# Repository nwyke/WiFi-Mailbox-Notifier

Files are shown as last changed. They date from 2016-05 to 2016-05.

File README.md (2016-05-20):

# WiFi Mailbox Notifier

This board notifies you when you get mail. JST-PH connector for 3.7V lithium ion battery (min 500mA), USB connector for power and battery charging, auto-reset for ESP-module, battery voltage measurement. 

Inspired by [hal9k "postkasse overvaagning"](https://hal9k.dk/postkasse-overvaagning/). Boards can be found on [OSHPark](https://oshpark.com/shared_projects/7UJ1nXM0) (not tested yet!).

Please support us and open-source hardware by purchasing products from
[MiniElektro.dk](http://minielektro.dk)/[MiniElektro.se](http://minielektro.se).

Content
-------------------
* **/Hardware**
  * All Eagle design files (.brd, .sch)
  * PDF schematic
  * BOM

License
-------------------
The hardware is released under [Creative Commons ShareAlike 4.0 International](https://creativecommons.org/licenses/by-sa/4.0/).

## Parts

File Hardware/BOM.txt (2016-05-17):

Part Value        Device                Package                      Description          BTM_NEG BTM_POS PROD_ID    TOP_NEG TOP_POS VALUE 
C2   100nF        CAP1206               1206                         Capacitor                                                             
C4   10uF         CAP1206               1206                         Capacitor                                                             
C5   10uF         CAP1206               1206                         Capacitor                                                             
D1   16V          DIODE-ZENER16V        SOD-123                      Zener Diode                          DIO-12440                  16V   
D2   16V          DIODE-ZENER16V        SOD-123                      Zener Diode                          DIO-12440                  16V   
D3   16V          DIODE-ZENER16V        SOD-123                      Zener Diode                          DIO-12440                  16V   
D5   16V          DIODE-ZENER16V        SOD-123                      Zener Diode                          DIO-12440                  16V   
D6   YELLOW       LED-YELLOW1206        LED-1206                     Yellow SMD LEDs                      DIO-00820                  YELLOW
J1                M06SILK_FEMALE_PTH    1X06                         Header 6                             CONN-08437                       
J2                M02LOCK               1X02_LOCK                    Standard 2-pin 0.1"                                                   
J4                JST_2MM_MALE          JST-2-SMD                    Mates to single-cell -       +       CONN-11443 -       +             
R1   1K           RESISTOR1206          1206                         Resistor                                                              
R2   2K           RESISTOR1206          1206                         Resistor                                                              
R3   10K          RESISTOR1206          1206                         Resistor                                                              
R7   1M           RESISTOR1206          1206                         Resistor                                                              
R8   220          RESISTOR1206          1206                         Resistor                                                              
R9   10K          RESISTOR1206          1206                         Resistor                                                              
R10  10K          RESISTOR1206          1206                         Resistor                                                              
R11  10K          RESISTOR1206          1206                         Resistor                                                              
R12  10K          RESISTOR1206          1206                         Resistor                                                              
R13  10K          RESISTOR1206          1206                         Resistor                                                              
SW1               SWITCH_SPST_4_PINRECT TACTILE_SWITCH_SMD_4.6X2.8MM                                      SWCH-13065                       
U$3  USB-MICROB"  USB-MICROB"           USB-B-MICRO-SMD_V03                                               CONN-11752                       
U1                ESP12ESMD             ESP12E-SMD                   ESP12E Module                                                         
U3   V_REG_LDOSMD V_REG_LDOSMD          SOT23-5                      Voltage Regulator LD                                                  
U5   MCP73831     MCP73831              SOT23-5

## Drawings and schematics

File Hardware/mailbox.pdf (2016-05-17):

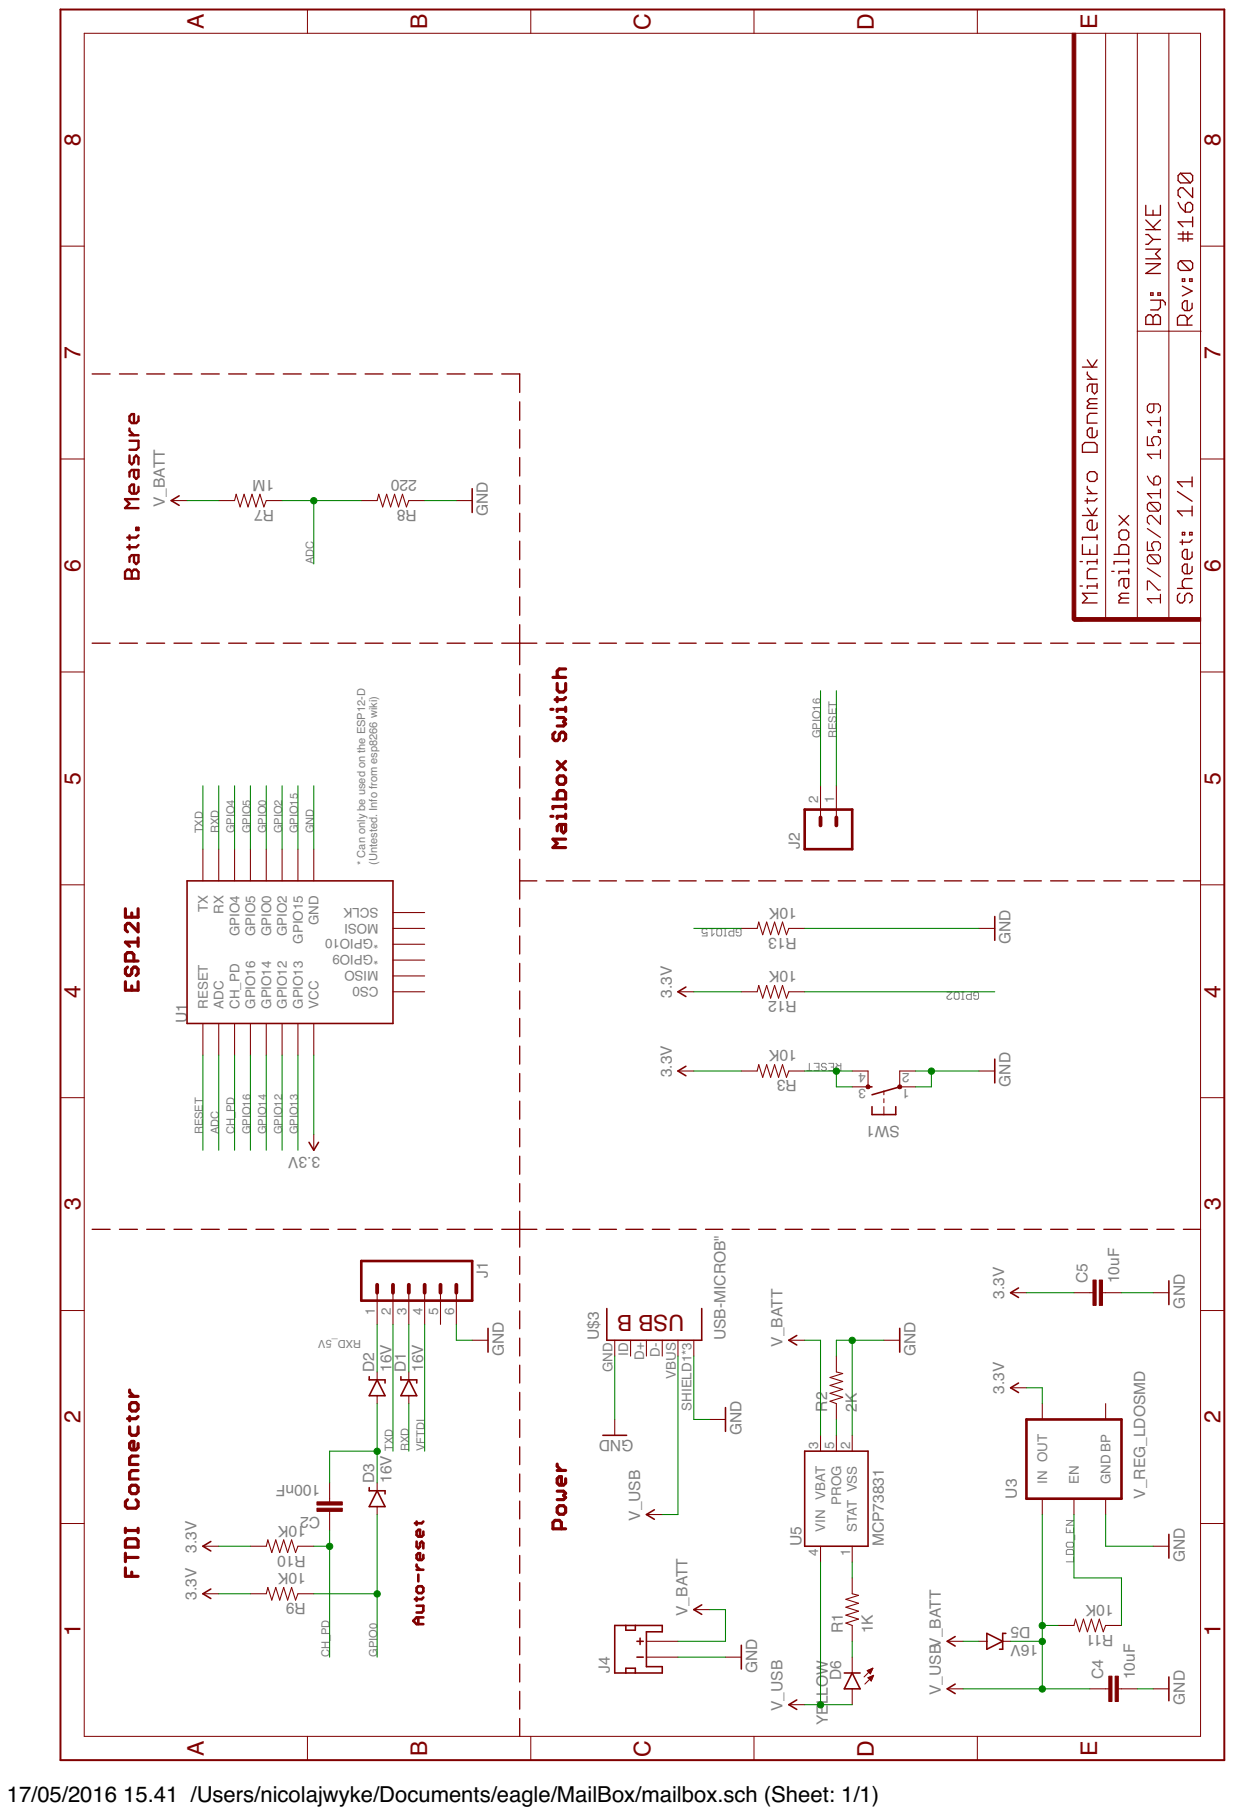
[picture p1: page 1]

* Can only be used on the ESP12-D

(Untested. Info from esp8266 wiki) GND

3.3V USB-MICROB" GND GND

17/05/2016 15.41 /Users/nicolajwyke/Documents/eagle/MailBox/mailbox.sch (Sheet: 1/1)

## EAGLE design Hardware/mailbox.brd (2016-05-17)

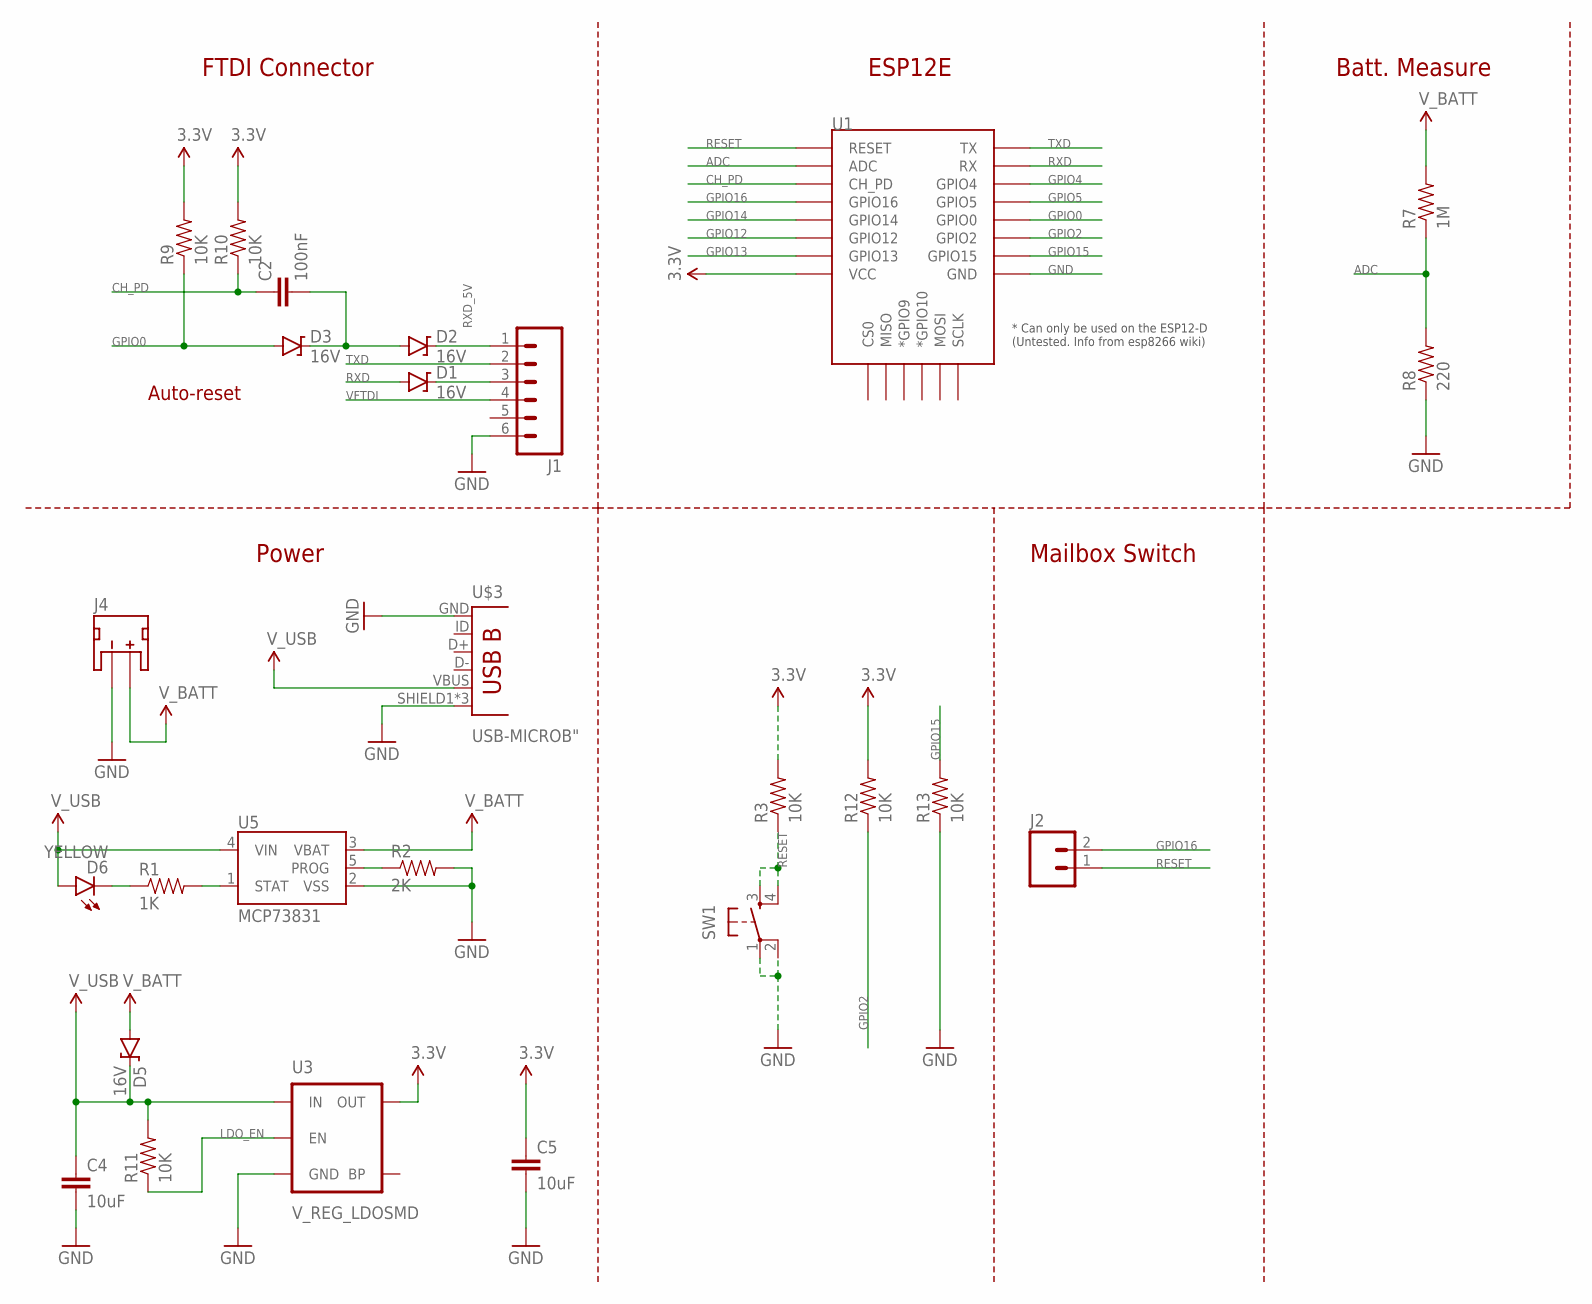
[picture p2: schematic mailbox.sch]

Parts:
C2: 100nF; 1206
C4, C5: 10uF; 1206
D1, D2, D3, D5: 16V; SOD-123
D6: YELLOW; LED-1206
J1: M06SILK_FEMALE_PTH; 1X06
J2: M02LOCK; 1X02_LOCK
J4: JST_2MM_MALE; JST-2-SMD
R1: 1K; 1206
R2: 2K; 1206
R3, R9, R10, R11, R12, R13: 10K; 1206
R7: 1M; 1206
R8: 220; 1206
SW1: SWITCH_SPST_4_PINRECT; TACTILE_SWITCH_SMD_4.6X2.8MM
U1: ESP12ESMD; ESP12E-SMD
U3: V_REG_LDOSMD; SOT23-5
U5: MCP73831; SOT23-5
U$3: USB-MICROB"; USB-B-MICRO-SMD_V03

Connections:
3.3V: C5.1, R3.2, R9.2, R10.2, R12.2, U1.VCC, U3.5 (OUT)
ADC: R7.1, R8.2, U1.ADC
CH_PD: C2.1, R10.1, U1.CH_PD
GND: C4.2, C5.2, J1.6, J4.1 (-), R2.2, R8.1, R13.1, SW1.1, SW1.2, U1.GND, U3.2 (GND), U5.2 (VSS), U$3.GND, U$3.SHIELD1 (SHIELD), U$3.SHIELD2 (SHIELD), U$3.SHIELD3 (SHIELD)
GPIO0: D3.A, R9.1, U1.GPIO0
GPIO2: R12.1, U1.GPIO2
GPIO4: U1.GPIO4
GPIO5: U1.GPIO5
GPIO12: U1.GPIO12
GPIO13: U1.GPIO13
GPIO14: U1.GPIO14
GPIO15: R13.2, U1.GPIO15
GPIO16: J2.2, U1.GPIO16
LDO_EN: R11.1, U3.3 (EN)
unnamed: D6.C, R1.1
unnamed: D2.C, J1.1
unnamed: C2.2, D2.A, D3.C
unnamed: R1.2, U5.1 (STAT)
unnamed: R2.1, U5.5 (PROG)
RESET: J2.1, R3.1, SW1.3, SW1.4, U1.RESET
RXD: D1.A, U1.RXD0 (RX)
RXD_5V: D1.C, J1.3
TXD: J1.2, U1.TXD0 (TX)
VFTDI: J1.4
V_BATT: D5.A, J4.2 (+), R7.2, U5.3 (VBAT)
V_USB: C4.1, D5.C, D6.A, R11.2, U3.1 (IN), U5.4 (VIN), U$3.VBUS

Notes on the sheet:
FTDI Connector
Auto-reset
ESP12E
Power
Mailbox Switch
Batt. Measure

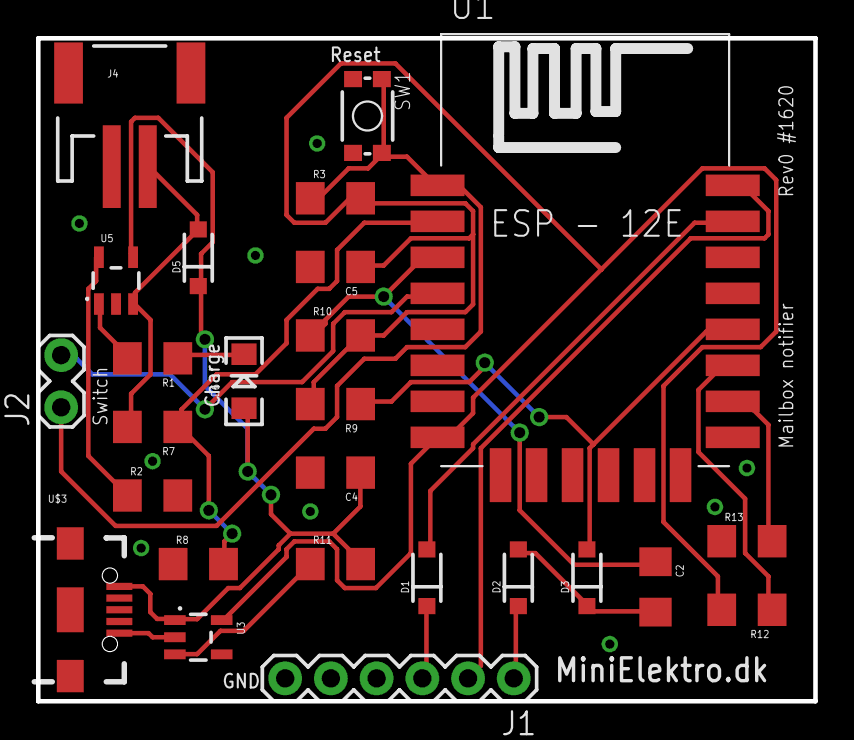
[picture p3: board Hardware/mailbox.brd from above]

Board: 2 copper layers, 43.2 x 36.8 mm, 26 parts (0 on the bottom side), 20 nets.

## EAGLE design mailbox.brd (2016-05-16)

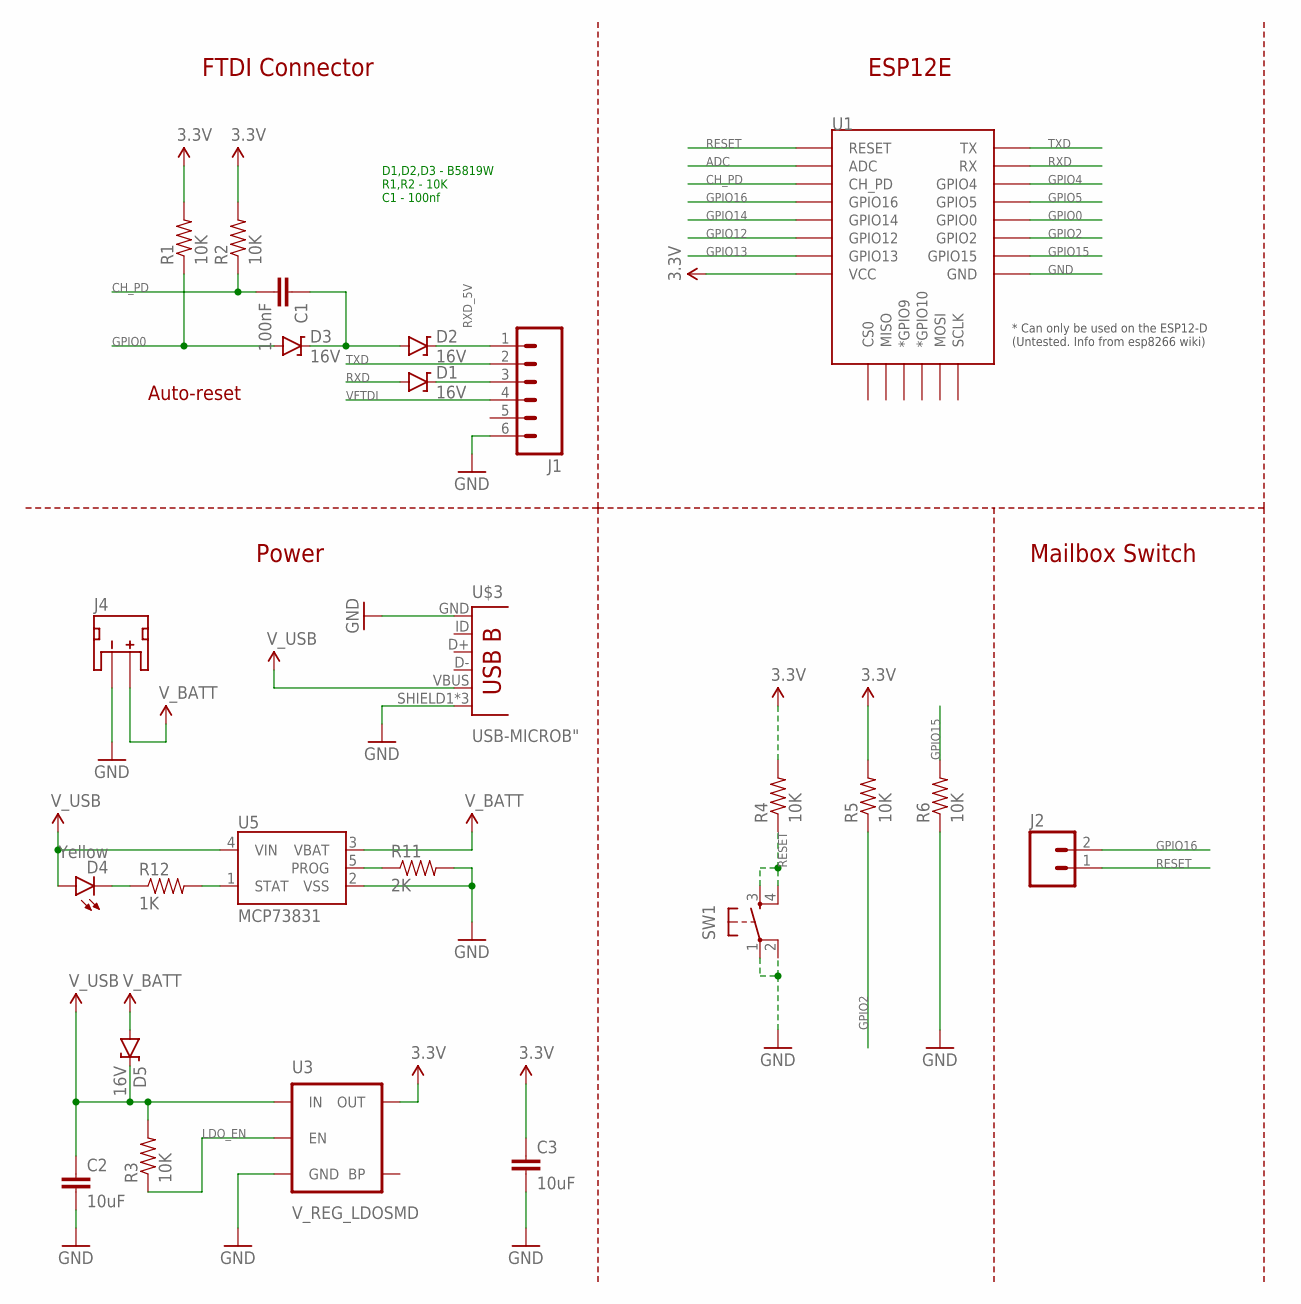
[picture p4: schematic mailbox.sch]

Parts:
C1: 100nF; 0402-CAP
C2, C3: 10uF; 0402-CAP
D1, D2, D3, D5: 16V; SOD-123
D4: Yellow; LED-0603
J1: M06SILK_FEMALE_PTH; 1X06
J2: M02LOCK; 1X02_LOCK
J4: JST_2MM_MALE; JST-2-SMD
R1, R2, R3, R4, R5, R6: 10K; 0402-RES
R11: 2K; 0603-RES
R12: 1K; 0603-RES
SW1: SWITCH_SPST_4_PINRECT; TACTILE_SWITCH_SMD_4.6X2.8MM
U1: ESP12ESMD; ESP12E-SMD
U3: V_REG_LDOSMD; SOT23-5
U5: MCP73831; SOT23-5
U$3: USB-MICROB"; USB-B-MICRO-SMD_V03

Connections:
3.3V: C3.1, R1.2, R2.2, R4.2, R5.2, U1.VCC, U3.5 (OUT)
ADC: U1.ADC
CH_PD: C1.2, R2.1, U1.CH_PD
GND: C2.2, C3.2, J1.6, J4.1 (-), R6.1, R11.2, SW1.1, SW1.2, U1.GND, U3.2 (GND), U5.2 (VSS), U$3.GND, U$3.SHIELD1 (SHIELD), U$3.SHIELD2 (SHIELD), U$3.SHIELD3 (SHIELD)
GPIO0: D3.A, R1.1, U1.GPIO0
GPIO2: R5.1, U1.GPIO2
GPIO4: U1.GPIO4
GPIO5: U1.GPIO5
GPIO12: U1.GPIO12
GPIO13: U1.GPIO13
GPIO14: U1.GPIO14
GPIO15: R6.2, U1.GPIO15
GPIO16: J2.2, U1.GPIO16
LDO_EN: R3.1, U3.3 (EN)
unnamed: D4.C, R12.1
unnamed: D2.C, J1.1
unnamed: C1.1, D2.A, D3.C
unnamed: R12.2, U5.1 (STAT)
unnamed: R11.1, U5.5 (PROG)
RESET: J2.1, R4.1, SW1.3, SW1.4, U1.RESET
RXD: D1.A, U1.RXD0 (RX)
RXD_5V: D1.C, J1.3
TXD: J1.2, U1.TXD0 (TX)
VFTDI: J1.4
V_BATT: D5.A, J4.2 (+), U5.3 (VBAT)
V_USB: C2.1, D4.A, D5.C, R3.2, U3.1 (IN), U5.4 (VIN), U$3.VBUS

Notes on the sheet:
D1,D2,D3 - B5819W R1,R2 - 10K C1 - 100nf
FTDI Connector
Auto-reset
ESP12E
Power
Mailbox Switch

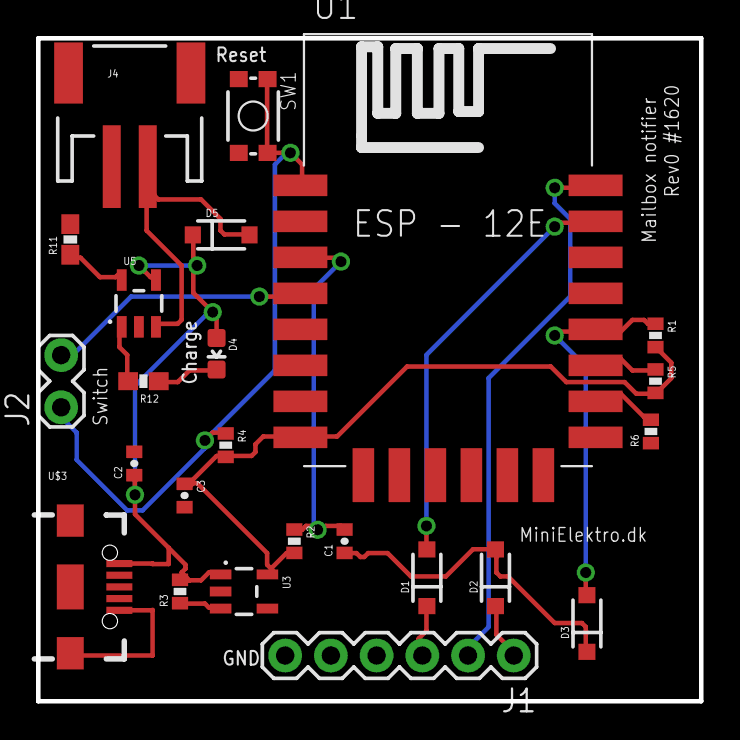
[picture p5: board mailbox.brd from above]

Board: 2 copper layers, 36.8 x 36.8 mm, 24 parts (0 on the bottom side), 19 nets.

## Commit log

2016-05-17 Added battery measure + PDF schematic
    [mailbox.brd, mailbox.sch]
2016-05-17 Create BOM

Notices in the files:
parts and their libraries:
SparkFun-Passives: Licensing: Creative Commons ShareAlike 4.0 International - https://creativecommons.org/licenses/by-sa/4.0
